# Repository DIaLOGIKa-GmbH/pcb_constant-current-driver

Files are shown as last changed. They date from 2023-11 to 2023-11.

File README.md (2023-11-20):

# LED Constant Current Driver Design

This project is part of [LibroDuct](https://www.libroduct.com/). We decided to publish some results of our LED driver designs to support the opensource maker scene. Feel free to use those results in your designs.

All those designs were tested with [9 IR-LEDs](https://jlcpcb.com/partdetail/Xssy-SE03_EMC3838AA60/C5205224) in series. These had a forward voltage of `14.0V`.

## LM3404 Constant Current Driver

The [LM3404 and LM3404HV](https://www.ti.com/lit/ds/symlink/lm3404.pdf) devices are monolithic switching regulators designed to deliver constant currents to high power LEDs. Ideal for automotive, industrial, and general lighting applications, these devices contain a high-side N-channel MOSFET switch with a current limit of 1.5A (typical) for step-down (Buck) regulators. Hysteretic controlled on-time and an external resistor allow the converter output voltage to adjust as needed to deliver a constant current to series and series-parallel connected LED arrays of varying number and type. 

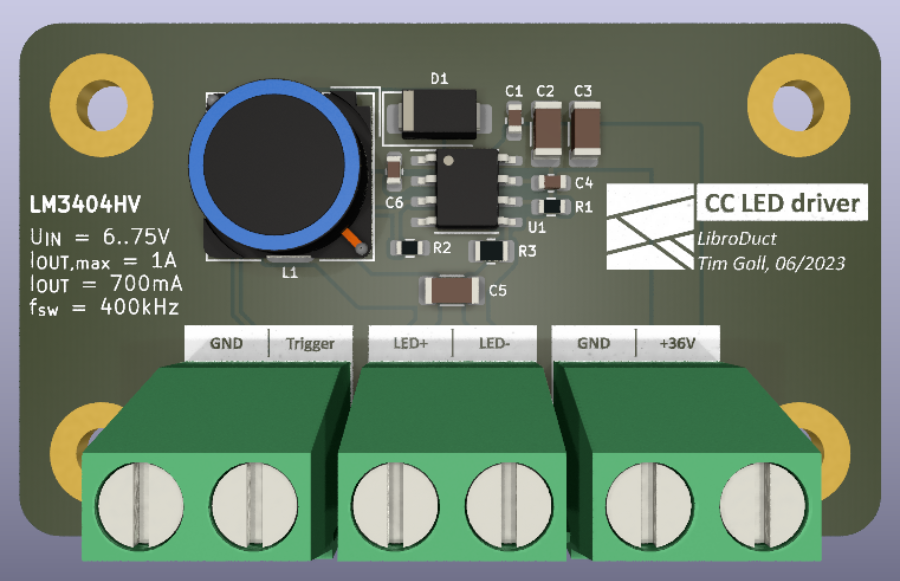
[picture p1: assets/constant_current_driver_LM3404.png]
constant current driver render

_(LM3404 testing PCB render)_

The layout of the PCB closely resembles the recommended design shown in the datasheet.

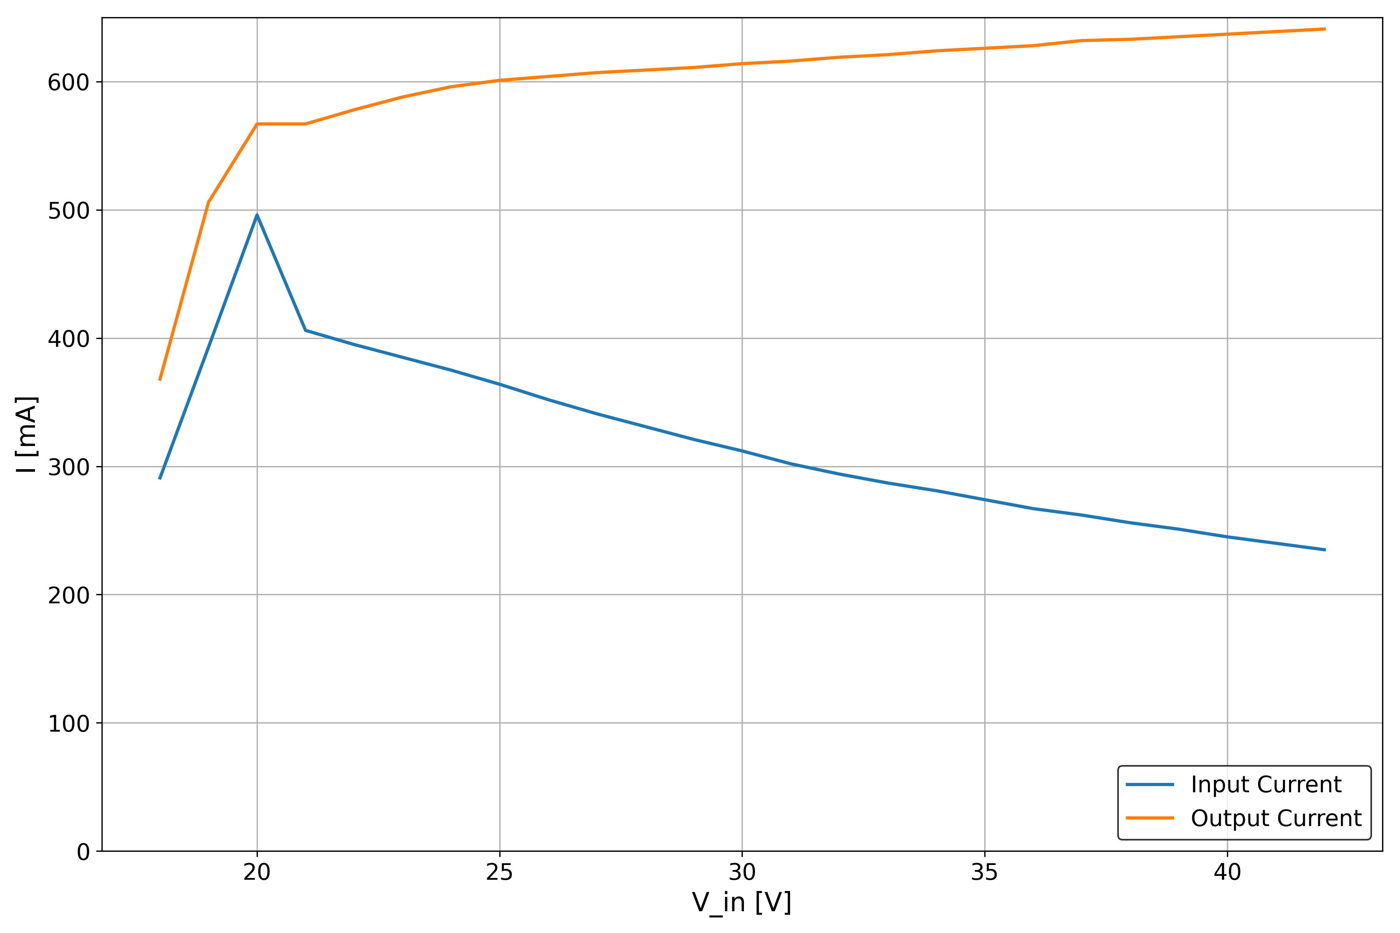
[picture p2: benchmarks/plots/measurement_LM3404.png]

_(LM3404 input and output current)_

As can be seen in this plot, the output current is not that stable when the input voltage is changed. This makes the chip unusable for applications with a varying input voltage.

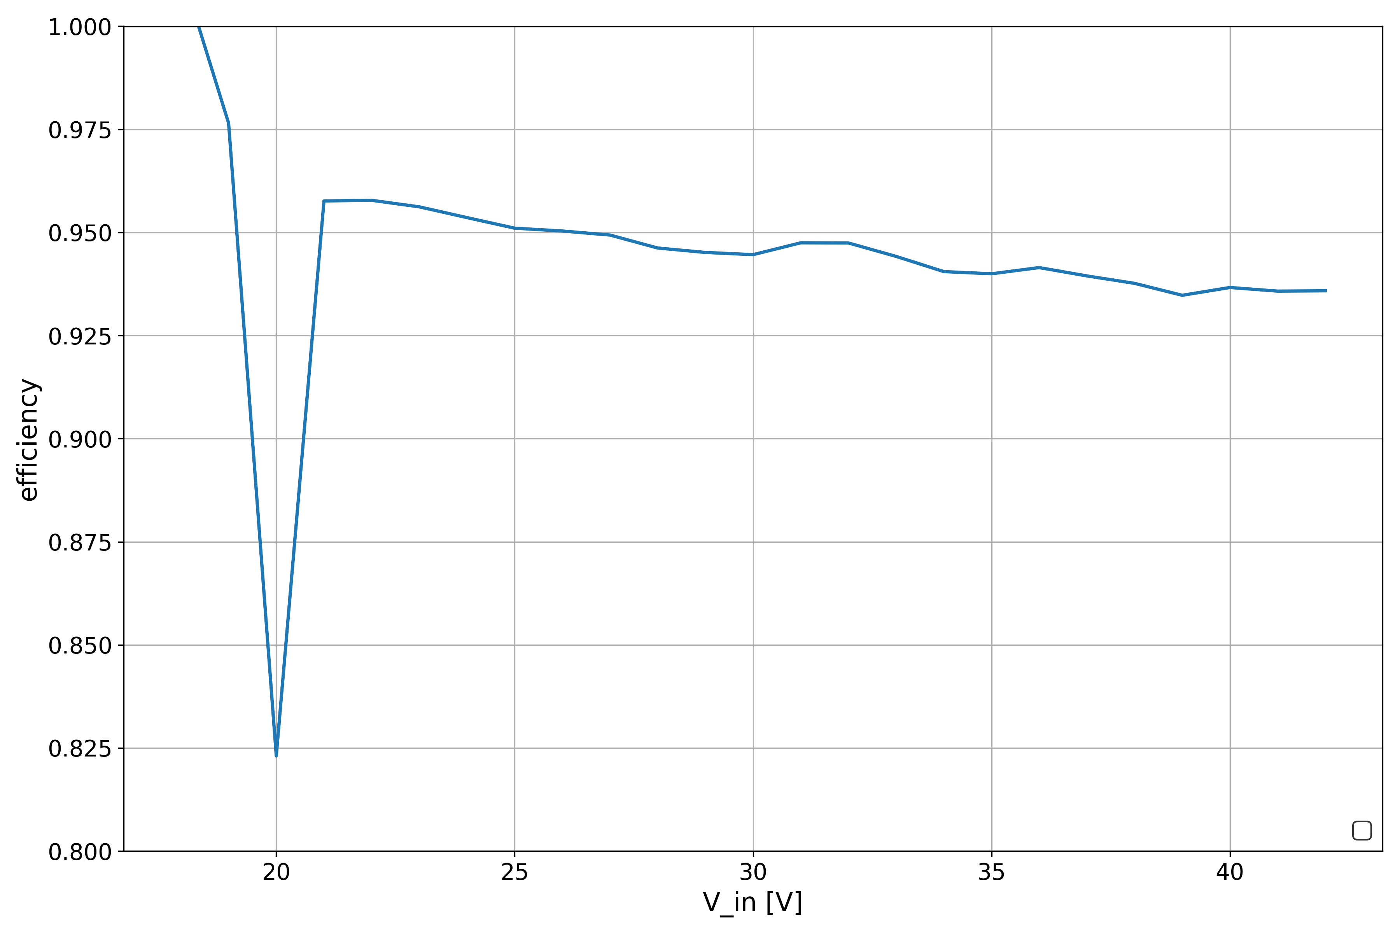
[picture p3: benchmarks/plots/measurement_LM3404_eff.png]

_(LM3404 efficiency)_

TODO: Replace graph with better data. Chip seems to be quite efficient.

## AL8860 Constant Current Driver

The [AL8860](https://www.diodes.com/assets/Datasheets/AL8860.pdf) is a hysteresis mode DC-DC step-down converter, designed for driving single or multiple series connected LEDs efficiently from a voltage source higher than the LED voltage. The device can operate from an input supply between `4.5V` and `40V` and provide an externally adjustable output current up to `1A` for TSOT25 package and `1.5A` for MSOP-8EP package.

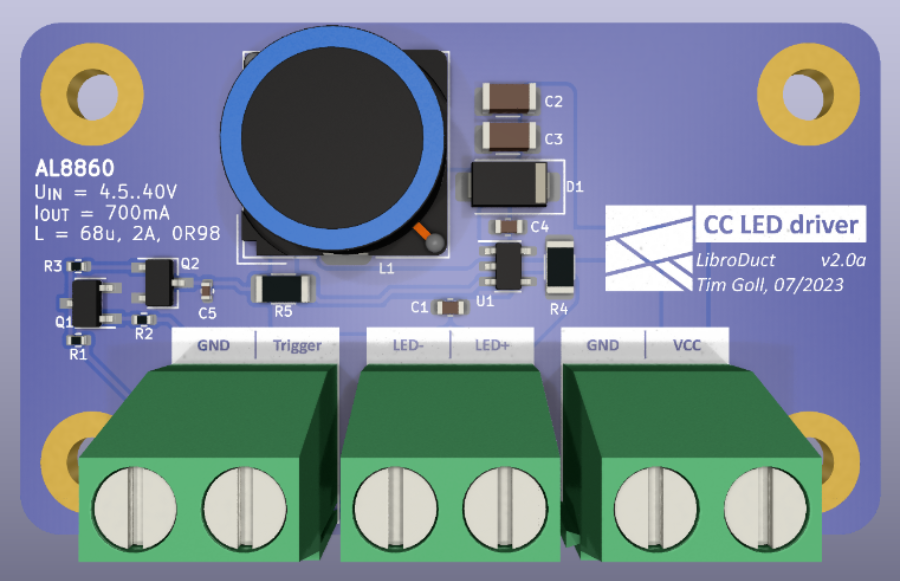
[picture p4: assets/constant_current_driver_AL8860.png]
constant current driver render

_(AL8860 testing PCB render)_

The curcuit designed is similar to the previous circuit but produces way better results thanks to the changed driving IC.

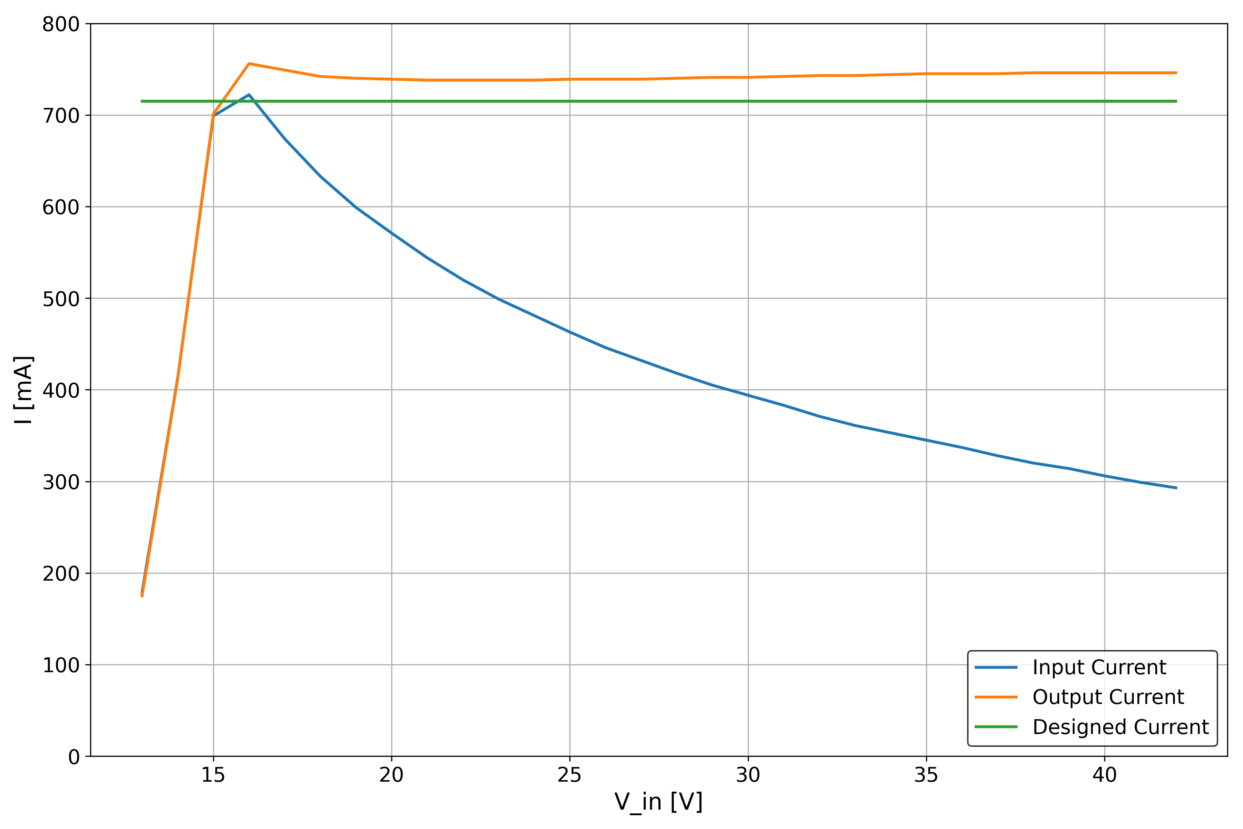
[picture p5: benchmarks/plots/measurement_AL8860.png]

_(AL8860 input and output current)_

The above plot shows the input and output current. The output current is rather stable over the supported input voltage. This makes the circuit suitable for our needs.

It is also worth mentioning that the output current is a bit higher than the designed current. This is fine in our usecase but it is something to be aware of.

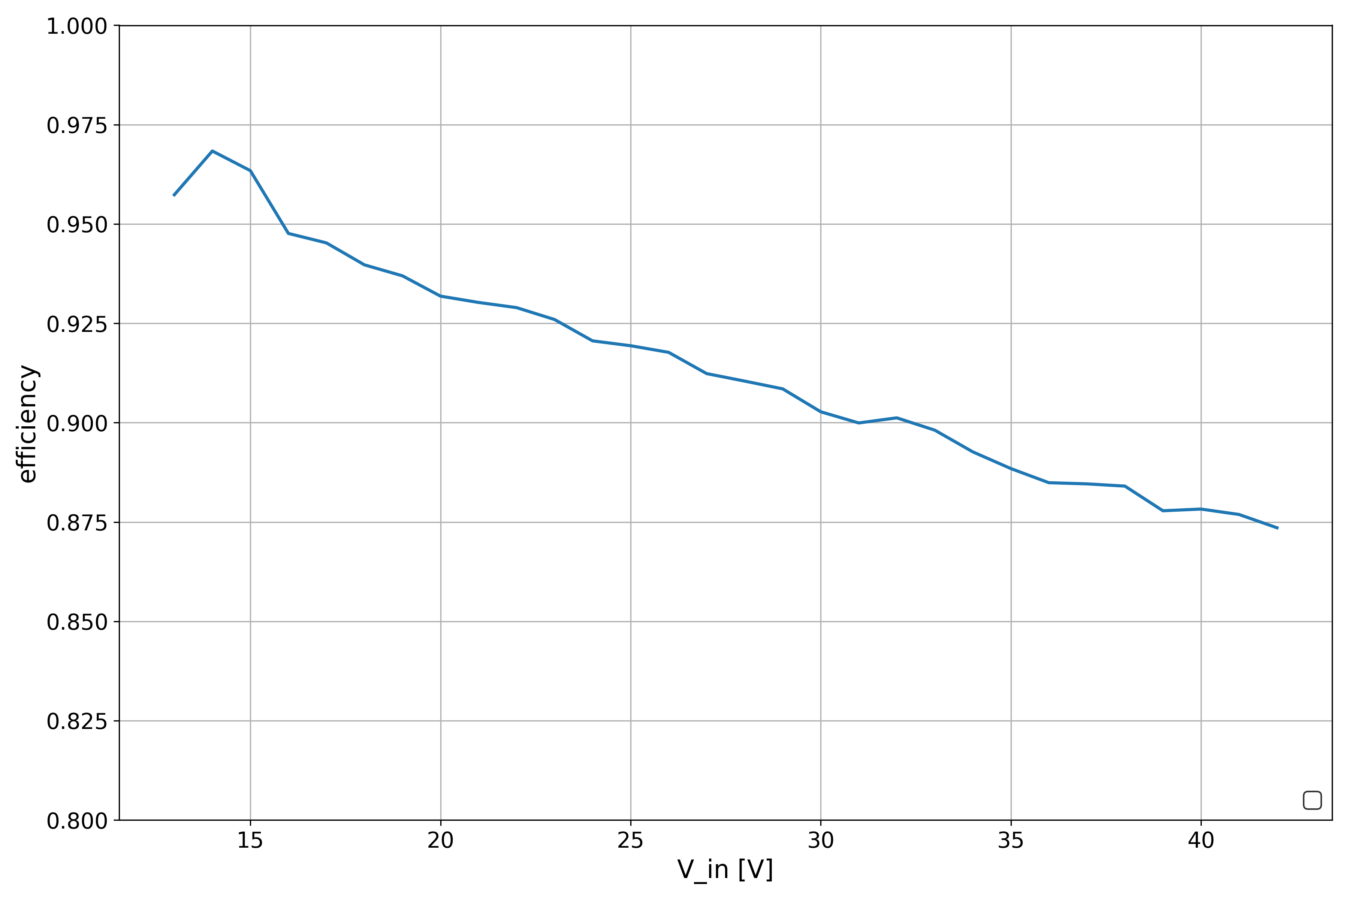
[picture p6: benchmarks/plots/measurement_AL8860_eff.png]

_(AL8860 driver efficiency at 700mA)_

### The Influence of Coil Selection

Another test we did with these drivers is so test and asses the influence of different coils on the efficiency. Especially the influence of the DC resistance.

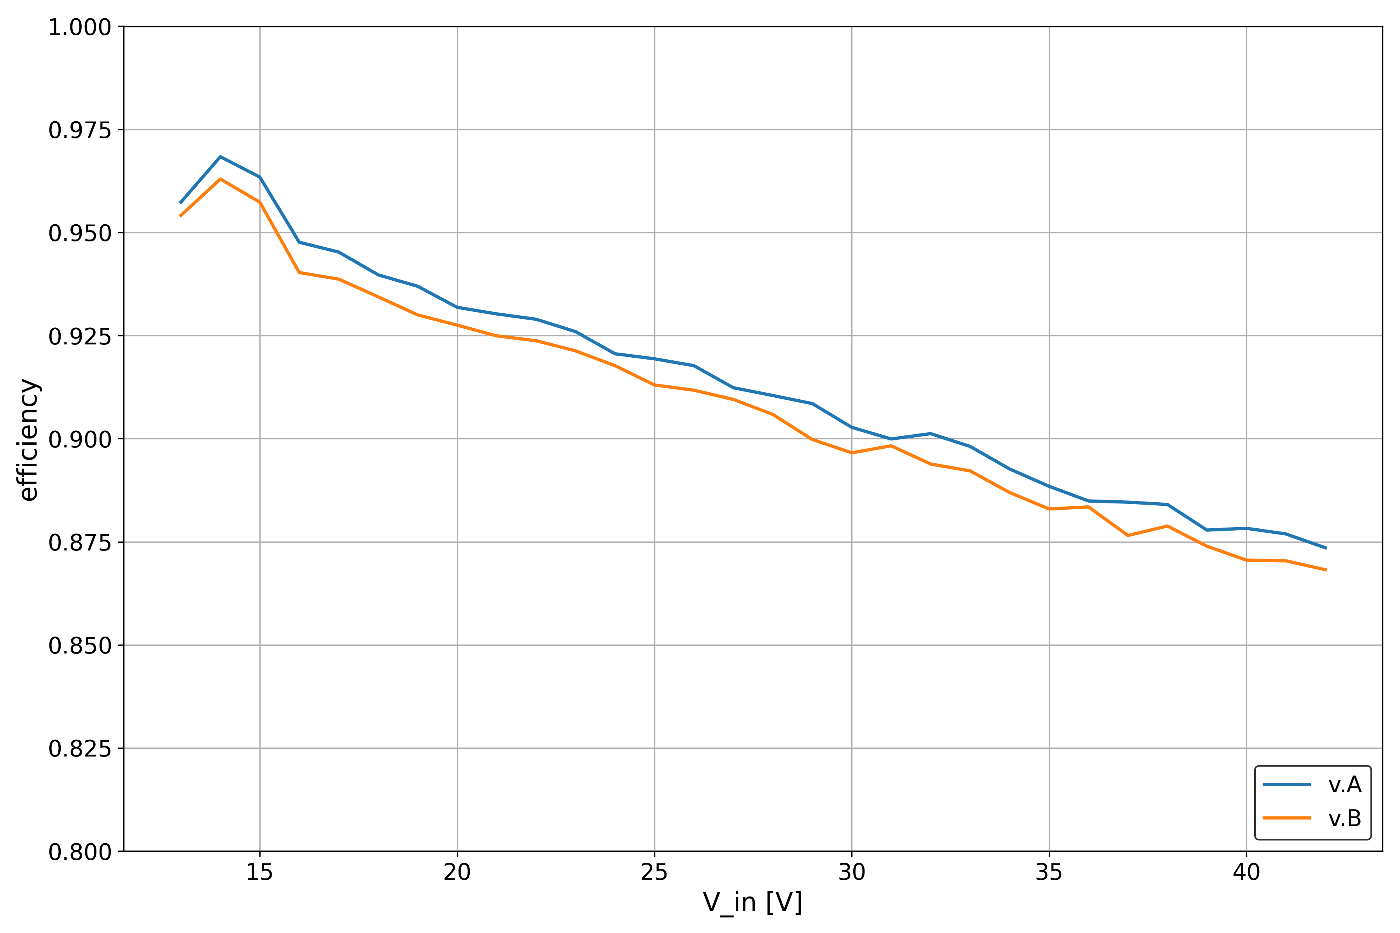
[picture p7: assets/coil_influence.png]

_(AL8860 driver efficiency when tested with different coils)_

The above plot shows the same AL8860 driver that was used previously, but we added another coil in the mix. `v.A` uses a coil with a DC resistance of `98mΩ`, `v.B` has a DC resistance of `201mΩ`. The inductance of both coils is identical.

It can be seen that the efficiency drops with higher DC resistance as this energy is lost in the form of heat created. It is therefore reasonable to use a bigger and better coil if the space is not constrained.

### 1.5A Driver with AL8860MP

There is also an `1.5A` version available of the driving IC. I tested it as well and got really good results. It seems to be a bit more efficient than the `700mA` version. This could also be due to two LED strings being in parallel or the lower value of the shunt resistor.

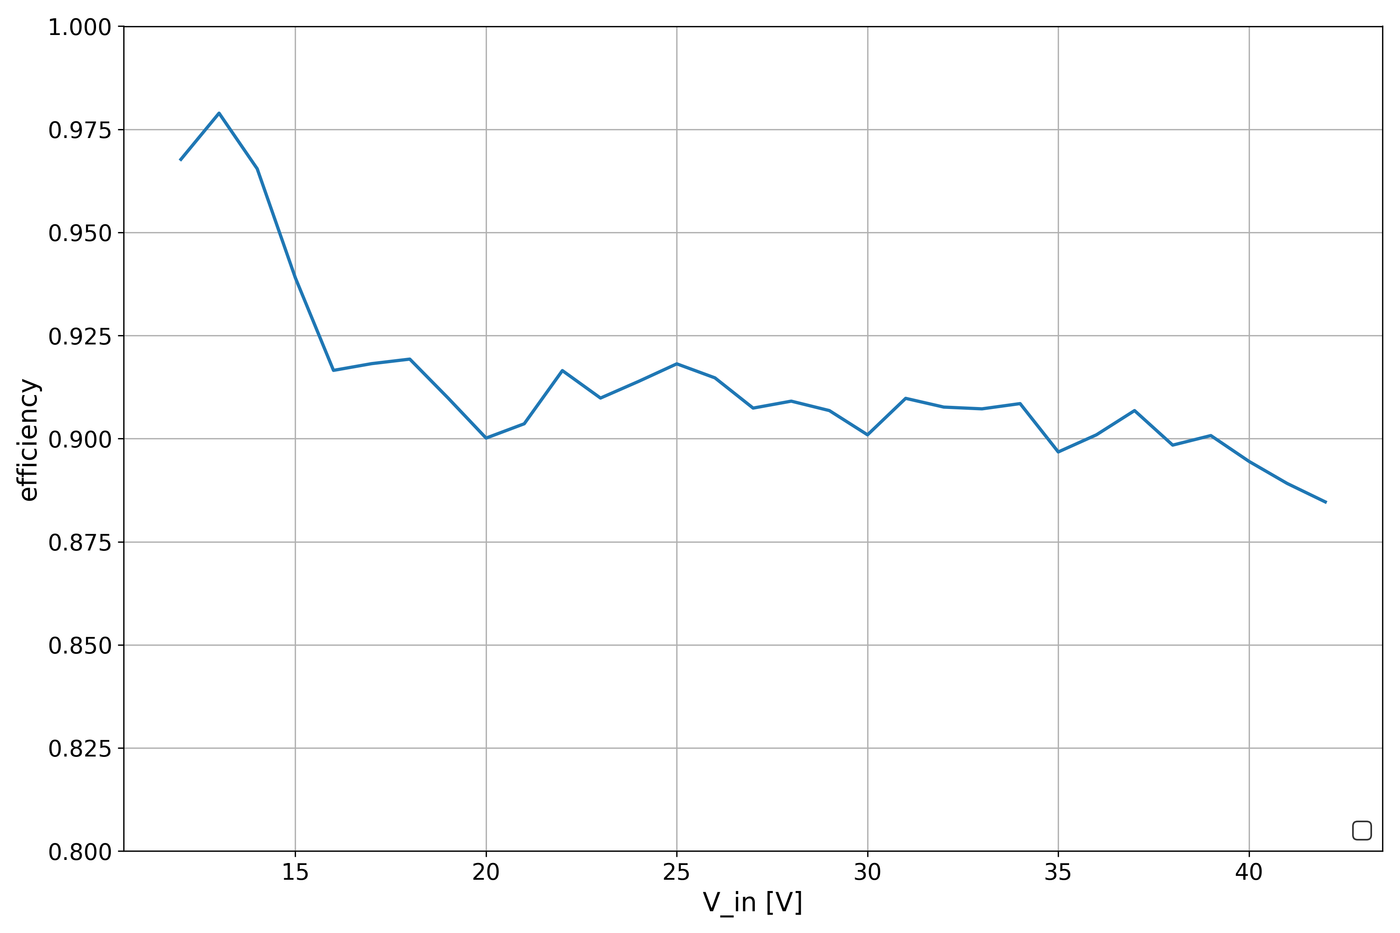
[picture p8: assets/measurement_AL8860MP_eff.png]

_(AL8860MP driver efficiency at 1.5A)_

### Comparison

There are many off-the-shelf LED driver modules available. One of them, the [Meanwell LDD700LS](https://www.meanwell-web.com/content/files/pdfs/productPdfs/MW/LDD-l/ldd-l-spec.pdf) was used here as a refernce point. When supplied with `36V` at `700mA` and a LED forward voltage of `14V`, it seems to have an efficieny of `87%`. Even in our worst case scenario our driver is more efficient.

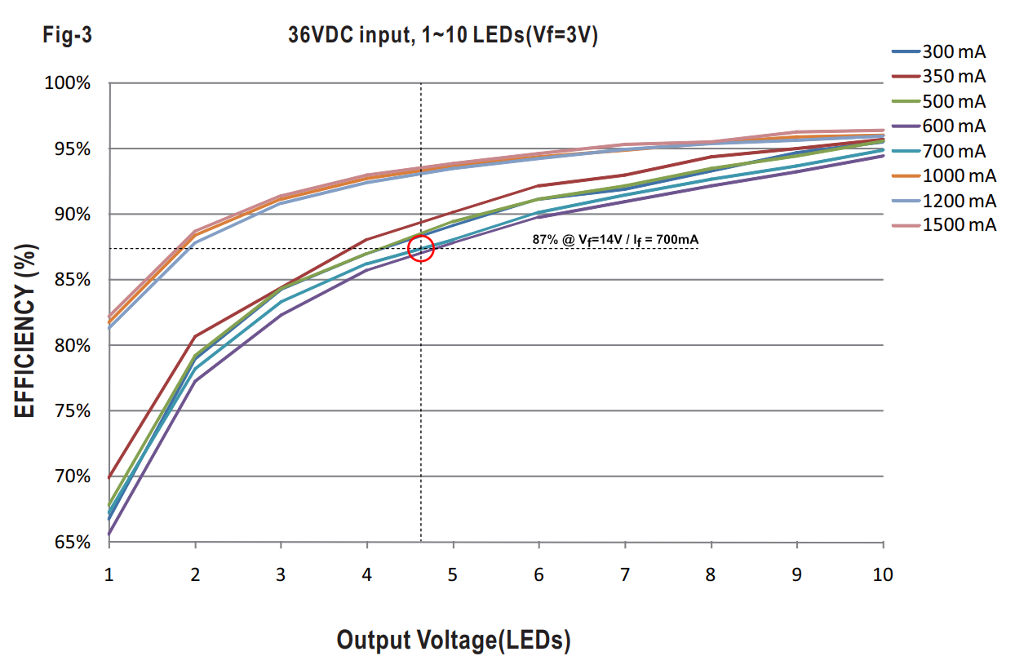
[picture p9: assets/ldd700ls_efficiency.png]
meanwell LDD700LS efficiency

_(LDD700LS driver module efficiency [fig 3, page 4])_

### Trigger Signals

Since the dimming pin of most LED driver ICs is open drain with a limited voltage range, we need additional circuitry to get what we need. Also many ICs support analog dimming with values over 100% if the internal ref voltage is surpassed which forces us to use the internal pullup.

The following circuit achieves all of that, while also supporting trigger voltages as high as VCC of the LED board, while also making sure that pulling the input to ground still disables it.

By default this circuit turns the device on and has to be actively turned off.

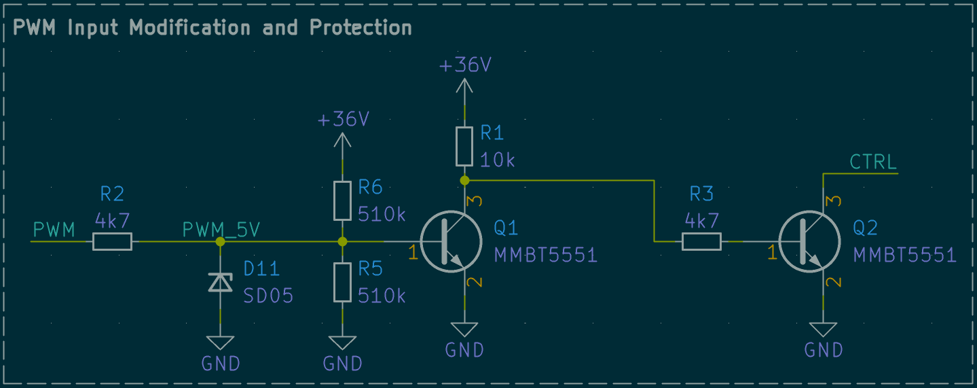
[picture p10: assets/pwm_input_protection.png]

_(PWM input modification schematic)_

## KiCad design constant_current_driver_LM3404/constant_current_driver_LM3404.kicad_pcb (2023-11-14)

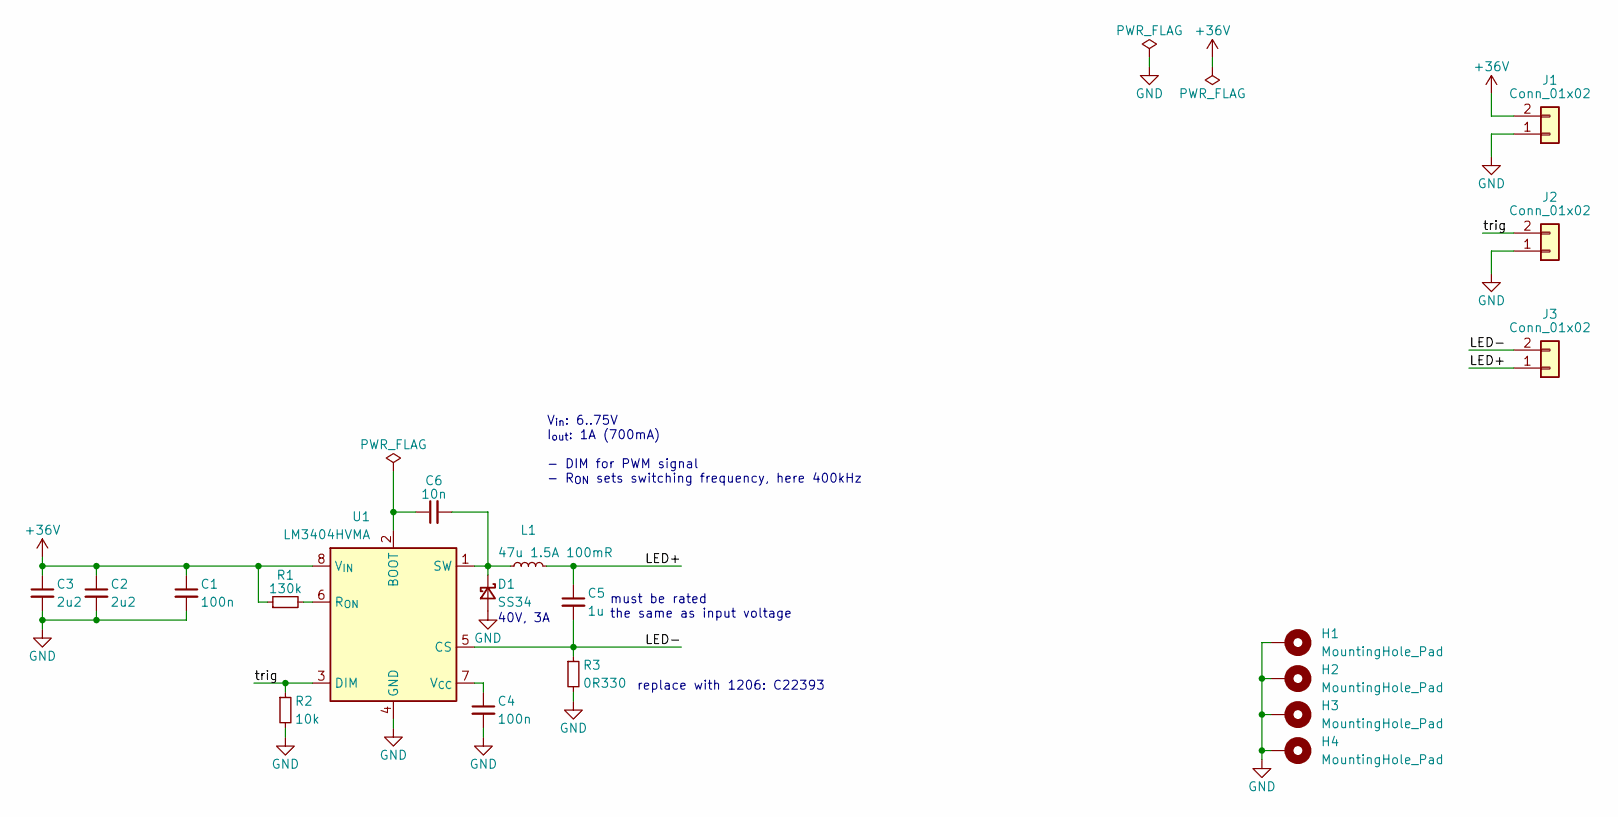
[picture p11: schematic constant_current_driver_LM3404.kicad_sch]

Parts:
C1, C4: 100n; C_0603_1608Metric; LCSC Part # C14663
C2, C3: 2u2; C_1206_3216Metric; LCSC Part # C50254
C5: 1u; C_1206_3216Metric; LCSC Part # C1848
C6: 10n; C_0603_1608Metric; LCSC Part # C57112
D1: SS34; D_SMA; LCSC Part # C8678
H1, H2, H3, H4: MountingHole_Pad; MountingHole_3.2mm_M3_Pad_TopOnly; LCSC Part # DNP
J1, J2, J3: Conn_01x02; TerminalBlock_Phoenix_MKDS-1,5-2-5.08_1x02_P5.08mm_Horizont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; LCSC Part # C8465
L1: 47u 1.5A 100mR; L_TDK_SLF10145; LCSC Part # C329816
R1: 130k; R_0603_1608Metric; LCSC Part # C22795
R2: 10k; R_0603_1608Metric; LCSC Part # C25804
R3: 0R330; R_0805_2012Metric; LCSC Part # C724024
U1: LM3404HVMA; SOIC-8_3.9x4.9mm_P1.27mm; LCSC Part # C1554286

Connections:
+36V: C1.1, C2.1, C3.1, J1.2, R1.1, U1.8 (V_{IN})
/LED+: C5.1, J3.1, L1.2
/LED-: C5.2, J3.2, R3.1, U1.5 (CS)
/trig: J2.2, R2.1, U1.3 (DIM)
GND: C1.2, C2.2, C3.2, C4.2, D1.2 (A), H1.1, H2.1, H3.1, H4.1, J1.1, J2.1, R2.2, R3.2, U1.4 (GND)
unnamed: C6.2, D1.1 (K), L1.1, U1.1 (SW)
unnamed: C6.1, U1.2 (BOOT)
unnamed: R1.2, U1.6 (R_{ON})
unnamed: C4.1, U1.7 (V_{CC})

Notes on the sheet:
must be rated the same as input voltage
40V, 3A
replace with 1206: C22393
V_{in}: 6..75V I_{out}: 1A (700mA) - DIM for PWM signal - R_{ON} sets switching frequency, here 400kHz

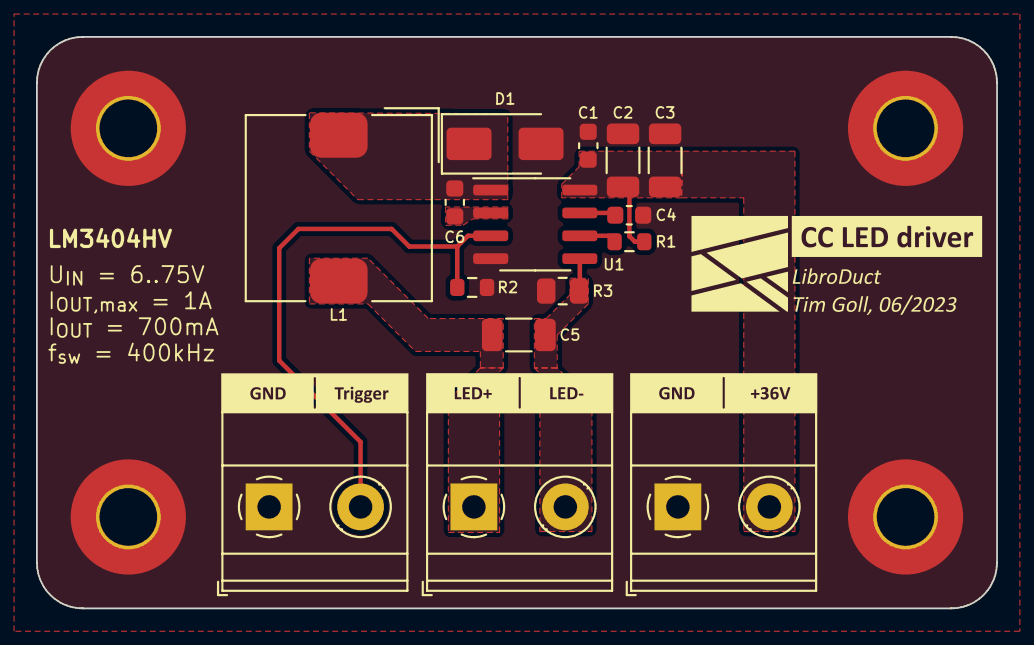
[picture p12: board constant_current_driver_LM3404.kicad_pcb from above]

Board: 2 copper layers, 53.3 x 31.8 mm, 19 parts (0 on the bottom side), 9 nets.

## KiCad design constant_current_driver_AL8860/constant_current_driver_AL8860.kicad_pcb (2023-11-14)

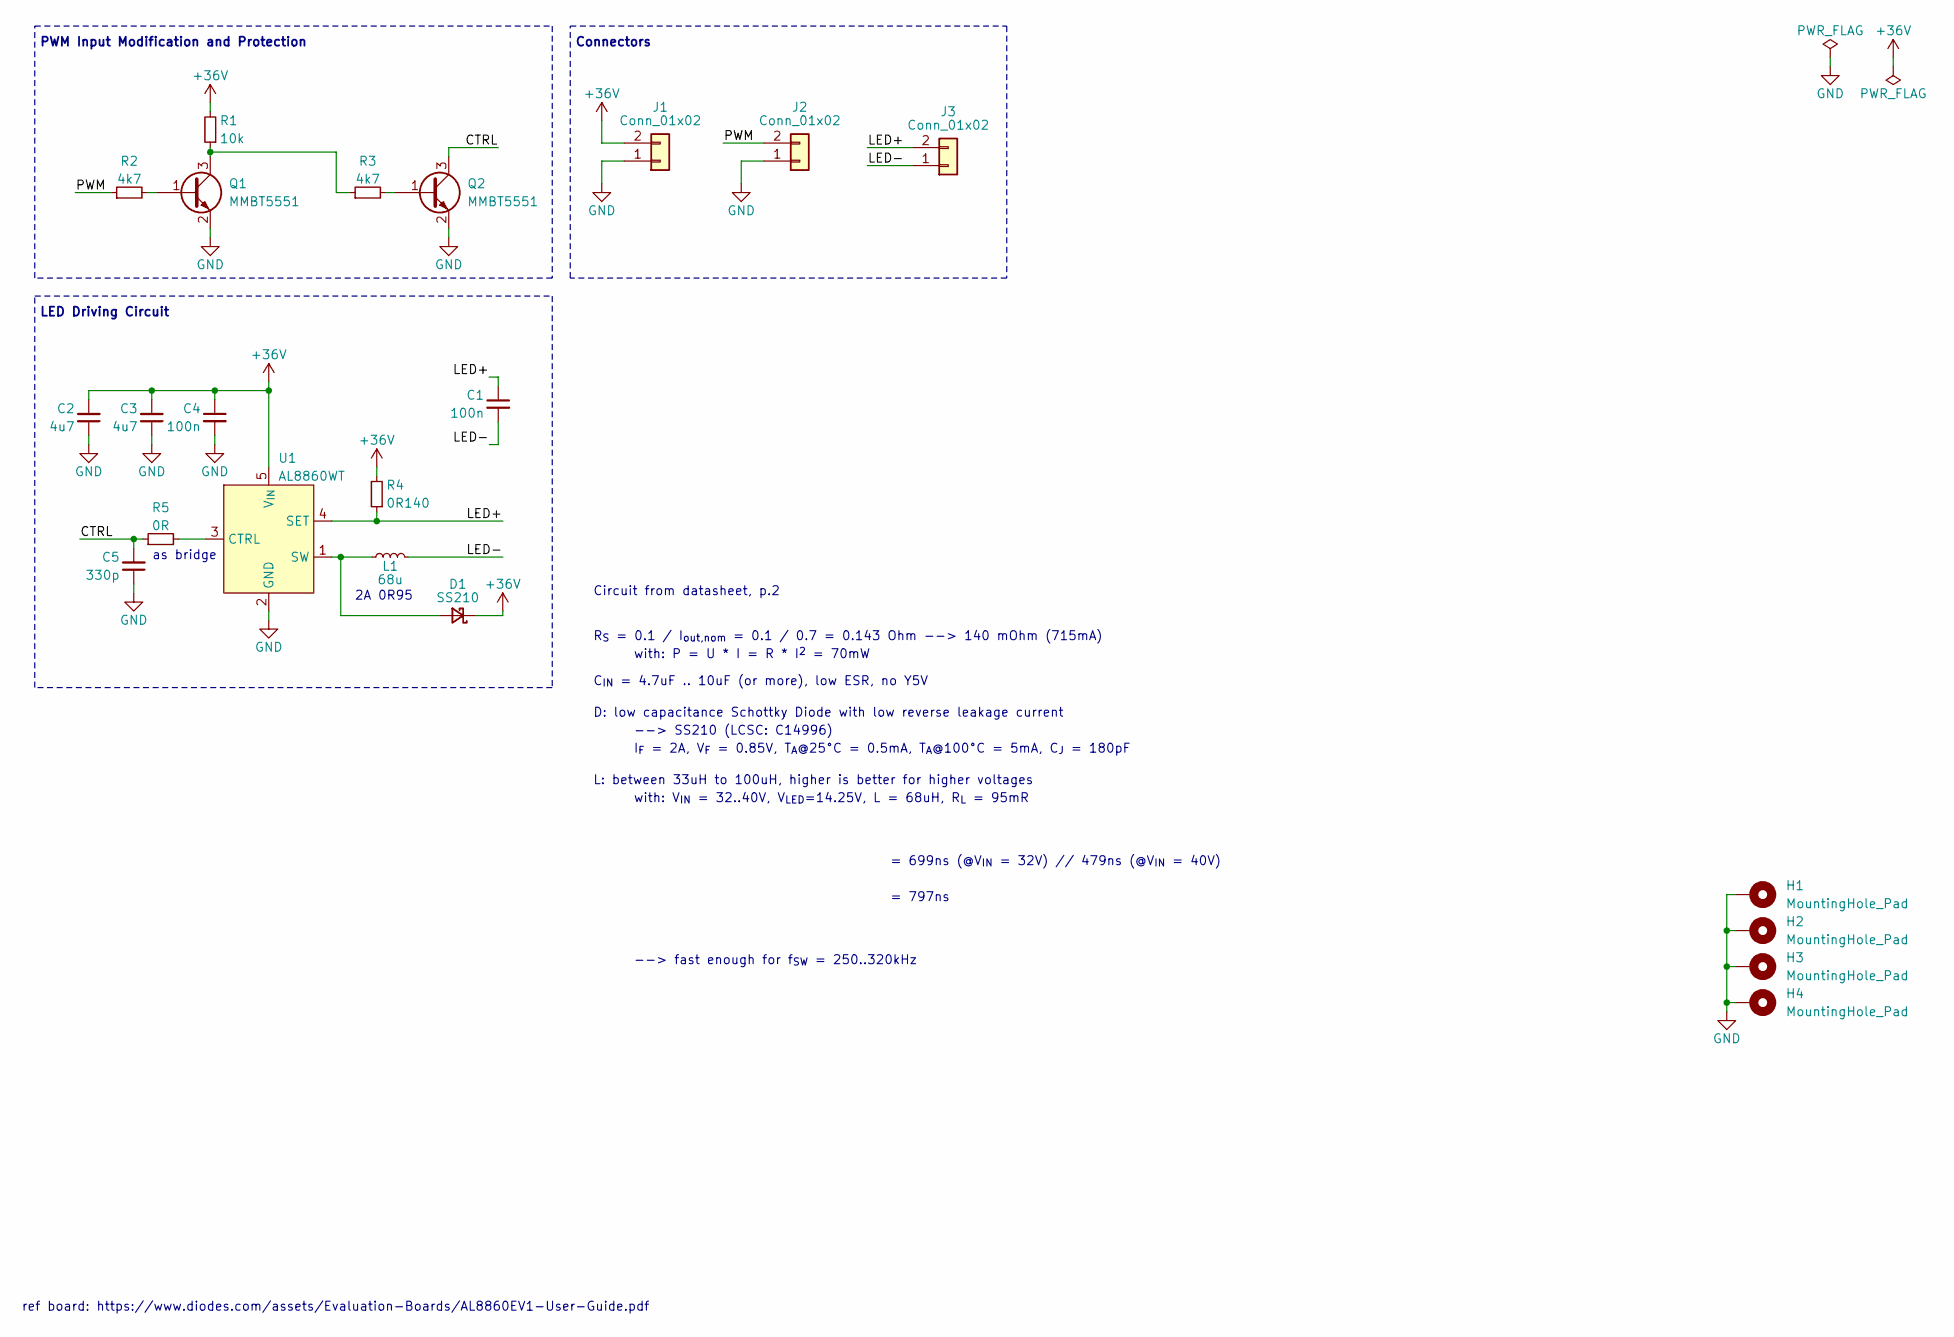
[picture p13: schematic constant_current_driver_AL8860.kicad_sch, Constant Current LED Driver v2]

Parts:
C1, C4: 100n; C_0603_1608Metric; LCSC Part # C14663
C2, C3: 4u7; C_1206_3216Metric; LCSC Part # C29823
C5: 330p; C_0402_1005Metric; LCSC Part # C13533
D1: SS210; D_SMA; LCSC Part # C14996
H1, H2, H3, H4: MountingHole_Pad; MountingHole_3.2mm_M3_Pad_TopOnly; LCSC Part # DNP
J1, J2, J3: Conn_01x02; TerminalBlock_Phoenix_MKDS-1,5-2-5.08_1x02_P5.08mm_Horizont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; LCSC Part # C8465
L1: 68u; L_TDK_SLF12565; LCSC Part # C693891
Q1, Q2: MMBT5551; TSOT-23; LCSC Part # C2145
R1: 10k; R_0402_1005Metric; LCSC Part # C25744
R2, R3: 4k7; R_0402_1005Metric; LCSC Part # C25900
R4: 0R140; R_1206_3216Metric; LCSC Part # C5138989
R5: 0R; R_1206_3216Metric; LCSC Part # C17888
U1: AL8860WT; TSOT-23-5; LCSC Part # C125330

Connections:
+36V: C2.2, C3.2, C4.1, D1.1 (K), J1.2, R1.2, R4.2, U1.5 (V_{IN})
/CTRL: C5.2, Q2.3 (C), R5.1
/LED+: C1.1, J3.2, R4.1, U1.4 (SET)
/LED-: C1.2, J3.1, L1.2
/PWM: J2.2, R2.1
GND: C2.1, C3.1, C4.2, C5.1, H1.1, H2.1, H3.1, H4.1, J1.1, J2.1, Q1.2 (E), Q2.2 (E), U1.2 (GND)
unnamed: D1.2 (A), L1.1, U1.1 (SW)
unnamed: Q1.1 (B), R2.2
unnamed: Q1.3 (C), R1.1, R3.1
unnamed: Q2.1 (B), R3.2
unnamed: R5.2, U1.3 (CTRL)

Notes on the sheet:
L: between 33uH to 100uH, higher is better for higher voltages
= 699ns (@V_{IN} = 32V) // 479ns (@V_{IN} = 40V)
R_{S} = 0.1 / I_{out,nom} = 0.1 / 0.7 = 0.143 Ohm --> 140 mOhm (715mA)
--> SS210 (LCSC: C14996)
as bridge
with: V_{IN} = 32..40V, V_{LED}=14.25V, L = 68uH, R_{L} = 95mR
2A 0R95
LED Driving Circuit
D: low capacitance Schottky Diode with low reverse leakage current
with: P = U * I = R * I^{2} = 70mW
I_{F} = 2A, V_{F} = 0.85V, T_{A}@25°C = 0.5mA, T_{A}@100°C = 5mA, C_{J} = 180pF
= 797ns
C_{IN} = 4.7uF .. 10uF (or more), low ESR, no Y5V
PWM Input Modification and Protection
--> fast enough for f_{SW} = 250..320kHz
Connectors
Circuit from datasheet, p.2
ref board: https://www.diodes.com/assets/Evaluation-Boards/AL8860EV1-User-Guide.pdf

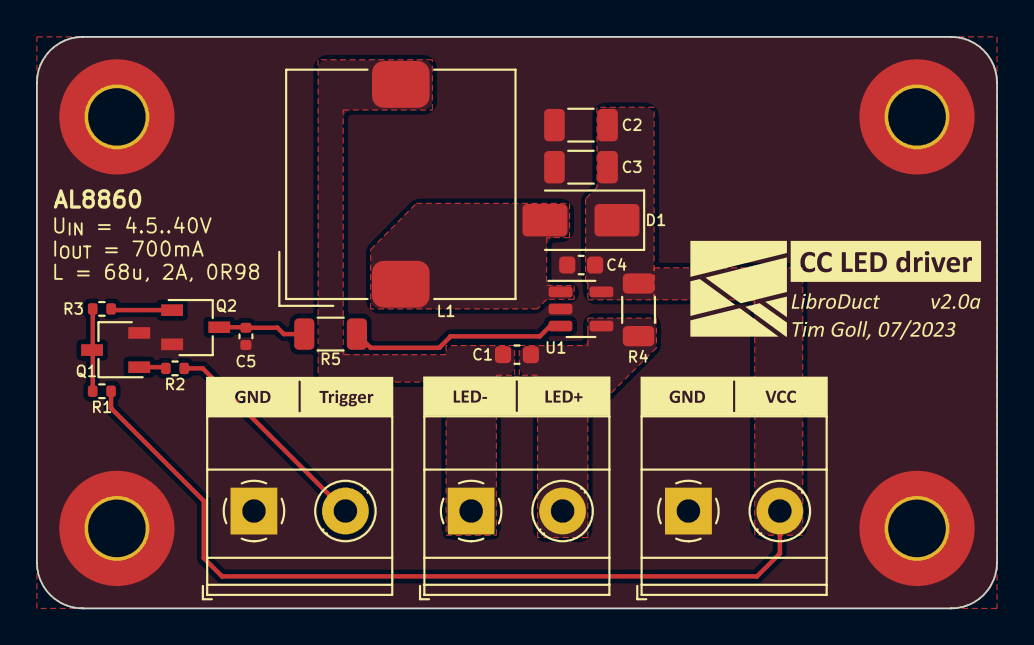
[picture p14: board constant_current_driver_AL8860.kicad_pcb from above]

Board: 2 copper layers, 53.3 x 31.8 mm, 22 parts (0 on the bottom side), 11 nets.

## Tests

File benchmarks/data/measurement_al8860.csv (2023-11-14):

V_in | V_out | I_in | I_out | I_des
13 | 12.73 | 179 | 175 | 715
14 | 13.59 | 413 | 412 | 715
15 | 14.41 | 699 | 701 | 715
16 | 14.48 | 722 | 756 | 715
17 | 14.46 | 674 | 749 | 715
18 | 14.43 | 633 | 742 | 715
19 | 14.41 | 599 | 740 | 715
20 | 14.40 | 571 | 739 | 715
21 | 14.40 | 544 | 738 | 715
22 | 14.40 | 520 | 738 | 715
23 | 14.40 | 499 | 738 | 715
24 | 14.40 | 481 | 738 | 715
25 | 14.40 | 463 | 739 | 715
26 | 14.40 | 446 | 739 | 715
27 | 14.40 | 432 | 739 | 715
28 | 14.40 | 418 | 740 | 715
29 | 14.40 | 405 | 741 | 715
30 | 14.40 | 394 | 741 | 715
31 | 14.40 | 383 | 742 | 715
32 | 14.40 | 371 | 743 | 715
33 | 14.40 | 361 | 743 | 715
34 | 14.40 | 353 | 744 | 715
35 | 14.40 | 345 | 745 | 715
36 | 14.41 | 337 | 745 | 715
37 | 14.41 | 328 | 745 | 715
38 | 14.41 | 320 | 746 | 715
39 | 14.41 | 314 | 746 | 715
40 | 14.41 | 306 | 746 | 715
41 | 14.41 | 299 | 746 | 715
42 | 14.41 | 293 | 746 | 715

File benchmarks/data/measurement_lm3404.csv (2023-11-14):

V_in | I_in | I_out | V_out
18 | 291 | 368 | 14.43
19 | 393 | 506 | 14.41
20 | 496 | 567 | 14.40
21 | 406 | 567 | 14.40
22 | 395 | 578 | 14.40
23 | 385 | 588 | 14.40
24 | 375 | 596 | 14.40
25 | 364 | 601 | 14.40
26 | 352 | 604 | 14.40
27 | 341 | 607 | 14.40
28 | 331 | 609 | 14.40
29 | 321 | 611 | 14.40
30 | 312 | 614 | 14.40
31 | 302 | 616 | 14.40
32 | 294 | 619 | 14.40
33 | 287 | 621 | 14.40
34 | 281 | 624 | 14.40
35 | 274 | 626 | 14.40
36 | 267 | 628 | 14.41
37 | 262 | 632 | 14.41
38 | 256 | 633 | 14.41
39 | 251 | 635 | 14.41
40 | 245 | 637 | 14.41
41 | 240 | 639 | 14.41
42 | 235 | 641 | 14.41

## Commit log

2023-11-14 moved AL8860 LED driver to repository
    [constant_current_driver_AL8860.kicad_pcb, constant_current_driver_AL8860.kicad_sch]
2023-11-14 added data
    [measurement.csv]
2023-11-14 added LM3404 driver
    [constant_current_driver_LM3404.kicad_pcb, constant_current_driver_LM3404.kicad_sch, measurement_al8860.csv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]
2023-11-15 made names upper case
